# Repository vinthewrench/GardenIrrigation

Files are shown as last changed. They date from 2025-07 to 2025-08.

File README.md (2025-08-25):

# GardenIrrigation

This is the hardware for Farm automation made easy as Pi

The entire series is at https://www.vinthewrench.com/p/off-grid-farm-automation-raspberry-pi

Garden Irrigation Board

<object data="Garden PCB schematic.pdf" type="application/pdf" width="600px" height="500px">
    <embed src="Garden PCB schematic.pdf">
        <p>This browser does not support PDFs. Please download the PDF to view it: <a href="Garden PCB schematic.pdf">Download PDF</a>.</p>
    </embed>
</object>

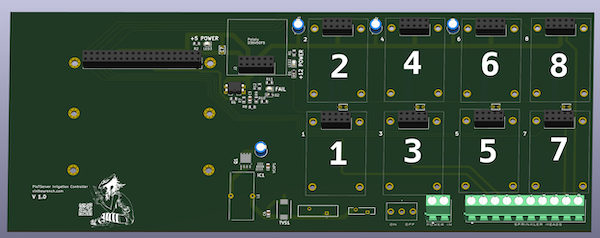
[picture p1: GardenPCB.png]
Garden Irrigation Board


DRV103 Plugin Board

<object data="DRV103 Solenoid Driver Board.pdf" type="application/pdf" width="600px" height="500px">
    <embed src="DRV103 Solenoid Driver Board.pdf">
        <p>This browser does not support PDFs. Please download the PDF to view it: <a href="DRV103 Solenoid Driver Board.pdf">Download PDF</a>.</p>
    </embed>
</object>

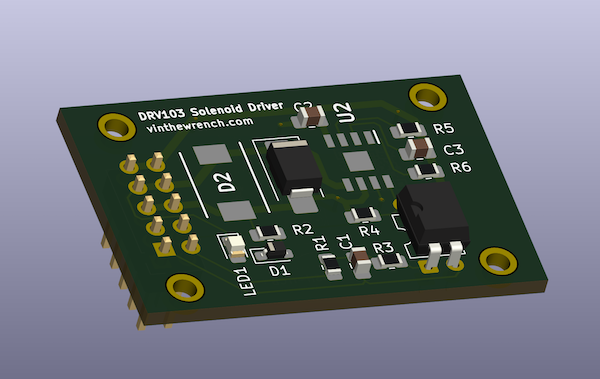
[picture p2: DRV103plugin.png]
DRV 103 Plugin


# Articles

* [Farm automation made easy as Pi](https://www.vinthewrench.com/p/raspberry-pi-internet-of-things-part)
* [Controlling the Irrigation valves.](https://www.vinthewrench.com/p/raspberry-pi-internet-of-things-part-23c)
* [Reading the Temperature with 1-wire Sensors](https://www.vinthewrench.com/p/raspberry-pi-internet-of-things-part-a4c)
* [Using the I2C protocol to communicate to sensors.](https://www.vinthewrench.com/p/raspberry-pi-internet-of-things-part-688)
* [Reading Environmental Data with I2C](https://www.vinthewrench.com/p/raspberry-pi-internet-of-things-part-a03)
* [Rain Sensors](https://www.vinthewrench.com/p/raspberry-pi-internet-of-things-part-cfd)
* [More I/O](https://www.vinthewrench.com/p/raspberry-pi-internet-of-things-part-61b)
* [Getting the data and controlling the devices from the REST API](https://www.vinthewrench.com/p/raspberry-pi-internet-of-things-part-8e7)
* [Writing your own device plug-ins](https://www.vinthewrench.com/p/raspberry-pi-internet-of-things-part-9ef)
* [Using software devices to build on the hardware.](https://www.vinthewrench.com/p/raspberry-pi-internet-of-things-part-094)
* [How to make things happen automatically](https://www.vinthewrench.com/p/raspberry-pi-internet-of-things-part-12f)
* [How to make things happen on time](https://www.vinthewrench.com/p/raspberry-pi-internet-of-things-part-eb8)
* [There are always conditions to evaluate](https://www.vinthewrench.com/p/raspberry-pi-internet-of-things-part-3aa)
* [Rolling my own I²C and 1-Wire interface card](https://www.vinthewrench.com/p/raspberry-pi-internet-of-things-part-2a8)

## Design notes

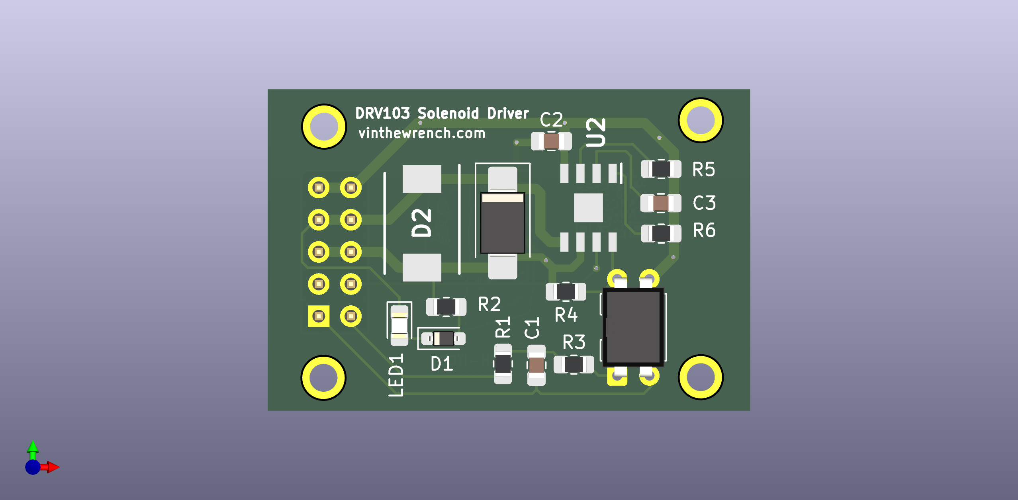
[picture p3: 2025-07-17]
DRV103 plugin/drvplugin.png

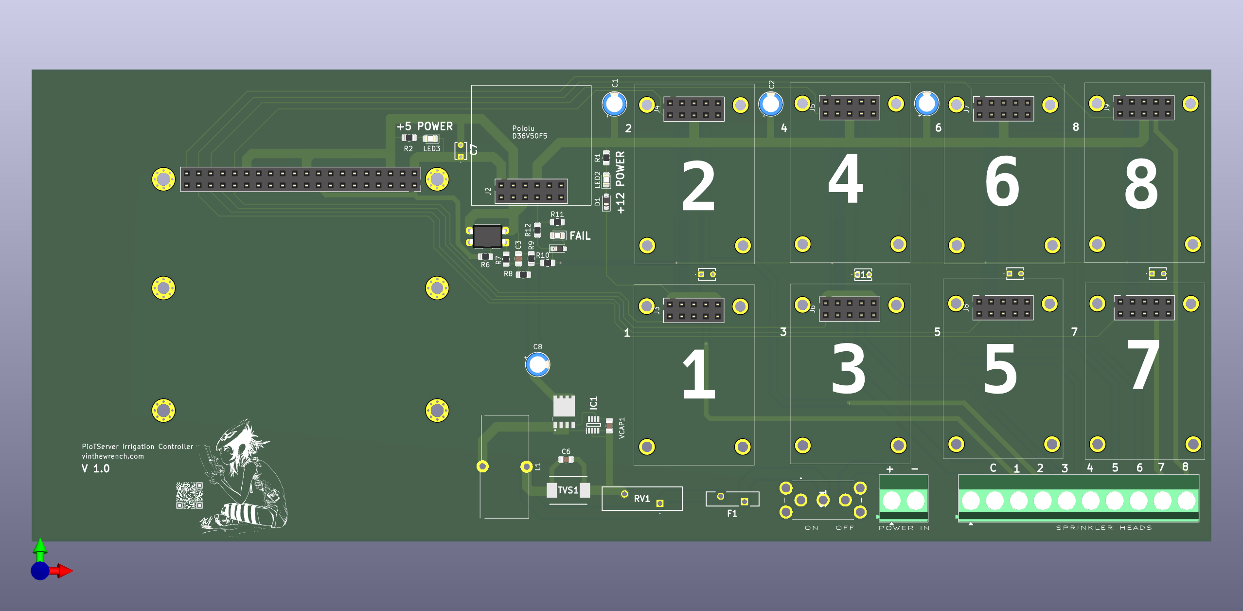
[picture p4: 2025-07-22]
Garden PCB/Garden PCB.png

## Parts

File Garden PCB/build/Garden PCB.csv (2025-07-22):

Id | Designator | Footprint | Quantity | Designation | Supplier and ref
1 | TVS1 | DIONM7959X262N | 1 | SMCJ60CA
2 | VCAP1,C6 | C_0805_2012Metric_Pad1.18x1.45mm_HandSolder | 2 | .1uf
3 | J8,J9,J5,J7,J3,J10,J6,J4 | PinSocket_2x05_P2.54mm_Vertical | 8 | Conn_02x05_Odd_Even
4 | LED1 | LED_0805_2012Metric_Pad1.15x1.40mm_HandSolder | 1 | APT2012SURCK
5 | J1 | PinSocket_2x20_P2.54mm_Vertical | 1 | GPIO
6 | C3 | C_0805_2012Metric_Pad1.18x1.45mm_HandSolder | 1 | .68uf
7 | R7 | R_0805_2012Metric_Pad1.20x1.40mm_HandSolder | 1 | 100
8 | D1,D2 | D_SOD-323_HandSoldering | 2 | 1N4148WS-7-F
9 | R8 | R_0805_2012Metric_Pad1.20x1.40mm_HandSolder | 1 | 150
10 | LED3,LED2 | LED_0805_2012Metric_Pad1.15x1.40mm_HandSolder | 2 | LG M67K-H1J2-24-Z
11 | C10,C11,C7,C5,C9 | RCER71H104K0DBH03A | 5 | .1uf
12 | R12 | R_0805_2012Metric_Pad1.20x1.40mm_HandSolder | 1 | 6.8K
13 | U1 | DIP-4_W7.62mm | 1 | PC817
14 | C1,C2,C4 | CP_Radial_D5.0mm_P2.00mm | 3 | 10uf
15 | C8 | CP_Radial_D5.0mm_P2.00mm | 1 | 220uf
16 | RV1 | V14E14AUTO | 1 | V14E14AUTO
17 | IC1 | SOT65P280X110-8N | 1 | LM74500QDDFRQ1
18 | L1 | L_Toroid_Vertical_L21.6mm_W9.1mm_P8.40mm_Bourns_5700 | 1 | 10 uH
19 | J2 | PinSocket_2x06_P2.54mm_Vertical | 1 | Conn_02x06_Top_Bottom
20 | F1 | RXEF0902 | 1 | RXEF090
21 | SW1 | 7105SYV3QE | 1 | SW_SPST
22 | R10 | R_0805_2012Metric_Pad1.20x1.40mm_HandSolder | 1 | 3.3K
23 | Q1 | CSD18532Q5BT | 1 | CSD18532Q5BT
24 | J12 | TerminalBlock_Phoenix_MKDS-1,5-2-5.08_1x02_P5.08mm_Horizontal | 1 | Screw_Terminal_01x02
25 | R2 | R_0805_2012Metric_Pad1.20x1.40mm_HandSolder | 1 | 330
26 | R1,R11 | R_0805_2012Metric_Pad1.20x1.40mm_HandSolder | 2 | 5.6K
27 | J11 | TerminalBlock_Phoenix_MKDS-1,5-10-5.08_1x10_P5.08mm_Horizontal | 1 | Screw_Terminal_01x10
28 | R9 | R_0805_2012Metric_Pad1.20x1.40mm_HandSolder | 1 | 1.8K
29 | R6 | R_0805_2012Metric_Pad1.20x1.40mm_HandSolder | 1 | 10K
30 | RP? | raspberrypi_2_3 | 1 | Raspberry_Pi_2_3

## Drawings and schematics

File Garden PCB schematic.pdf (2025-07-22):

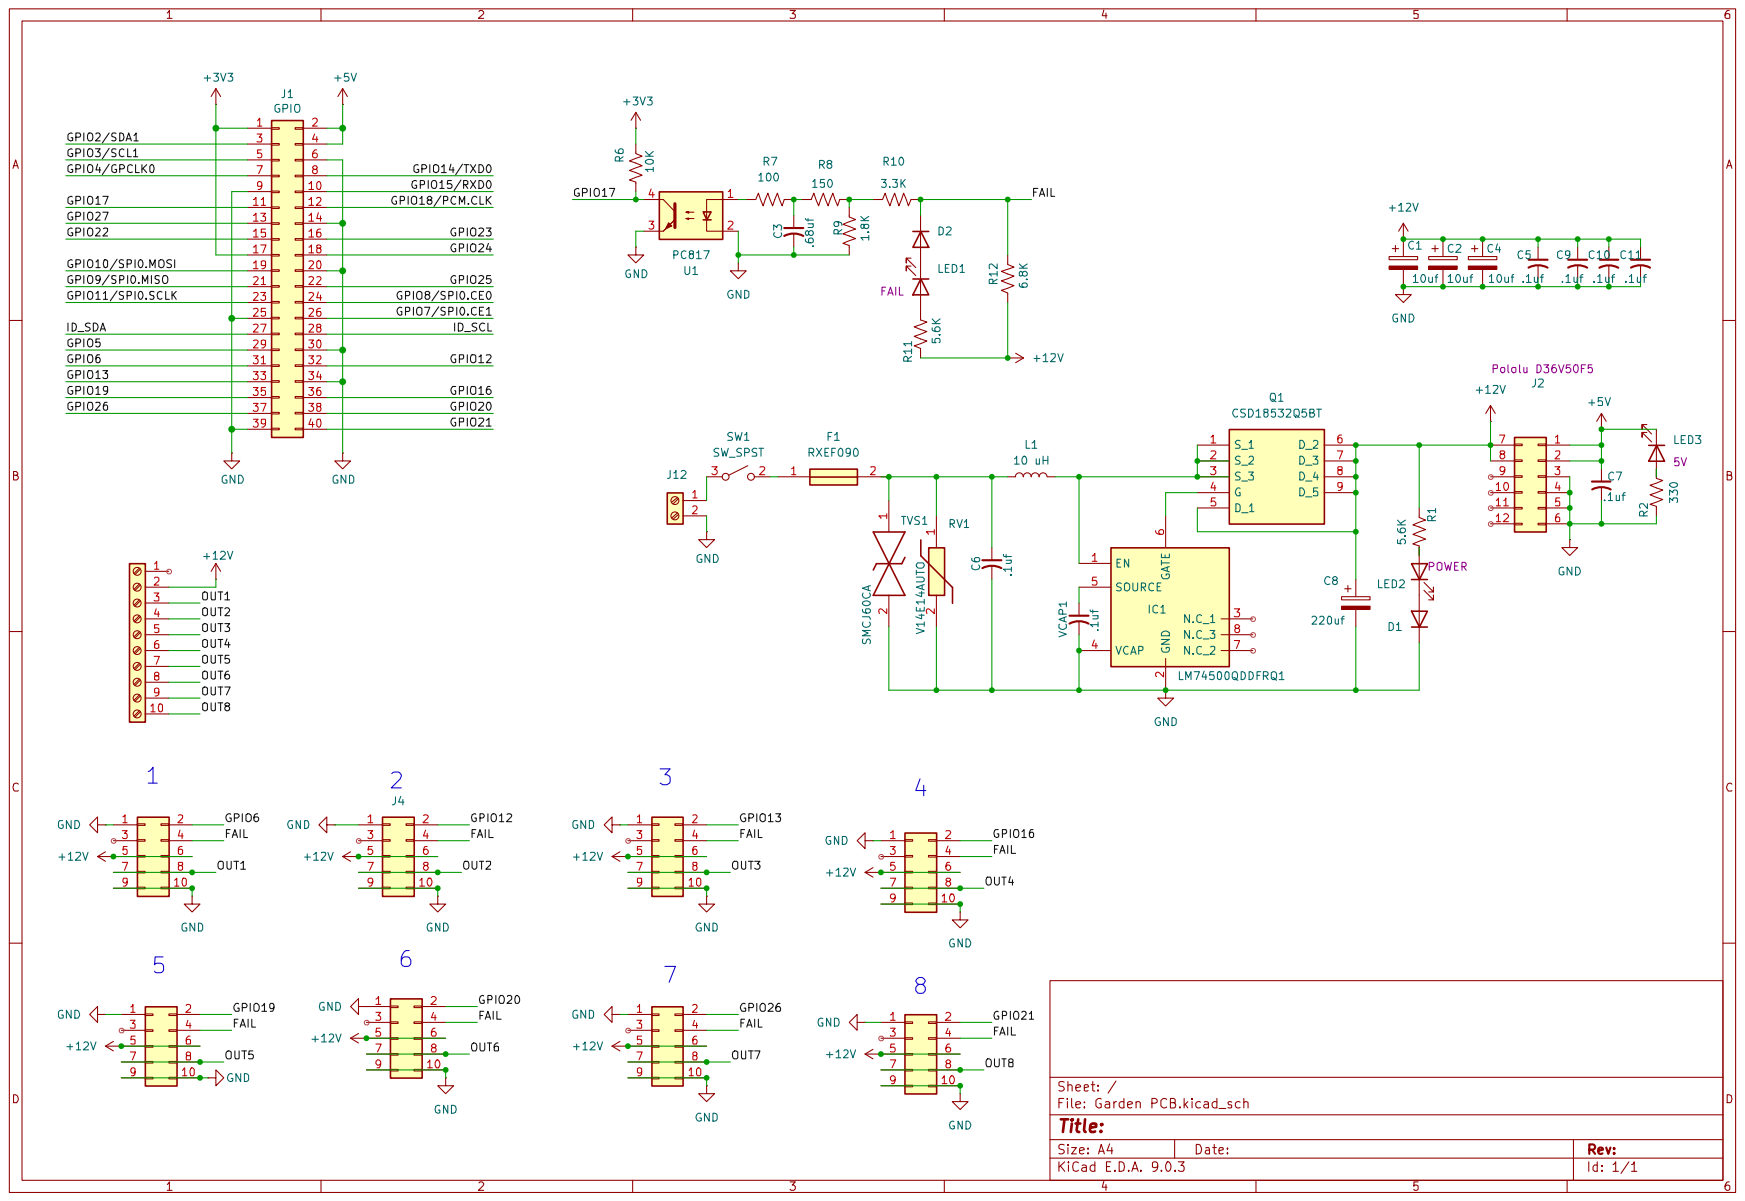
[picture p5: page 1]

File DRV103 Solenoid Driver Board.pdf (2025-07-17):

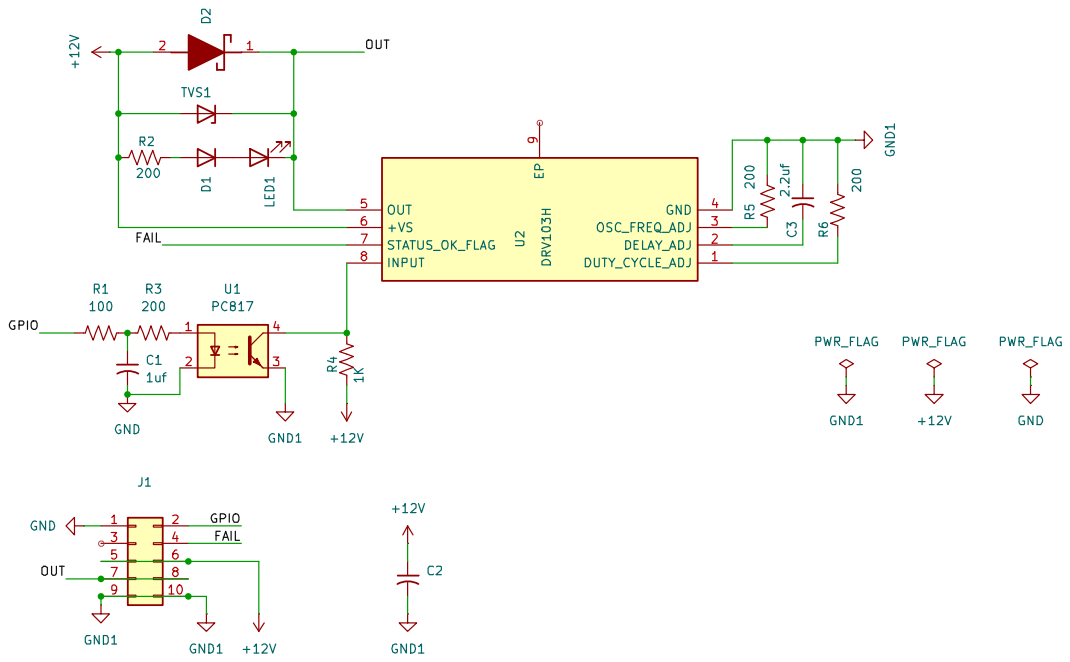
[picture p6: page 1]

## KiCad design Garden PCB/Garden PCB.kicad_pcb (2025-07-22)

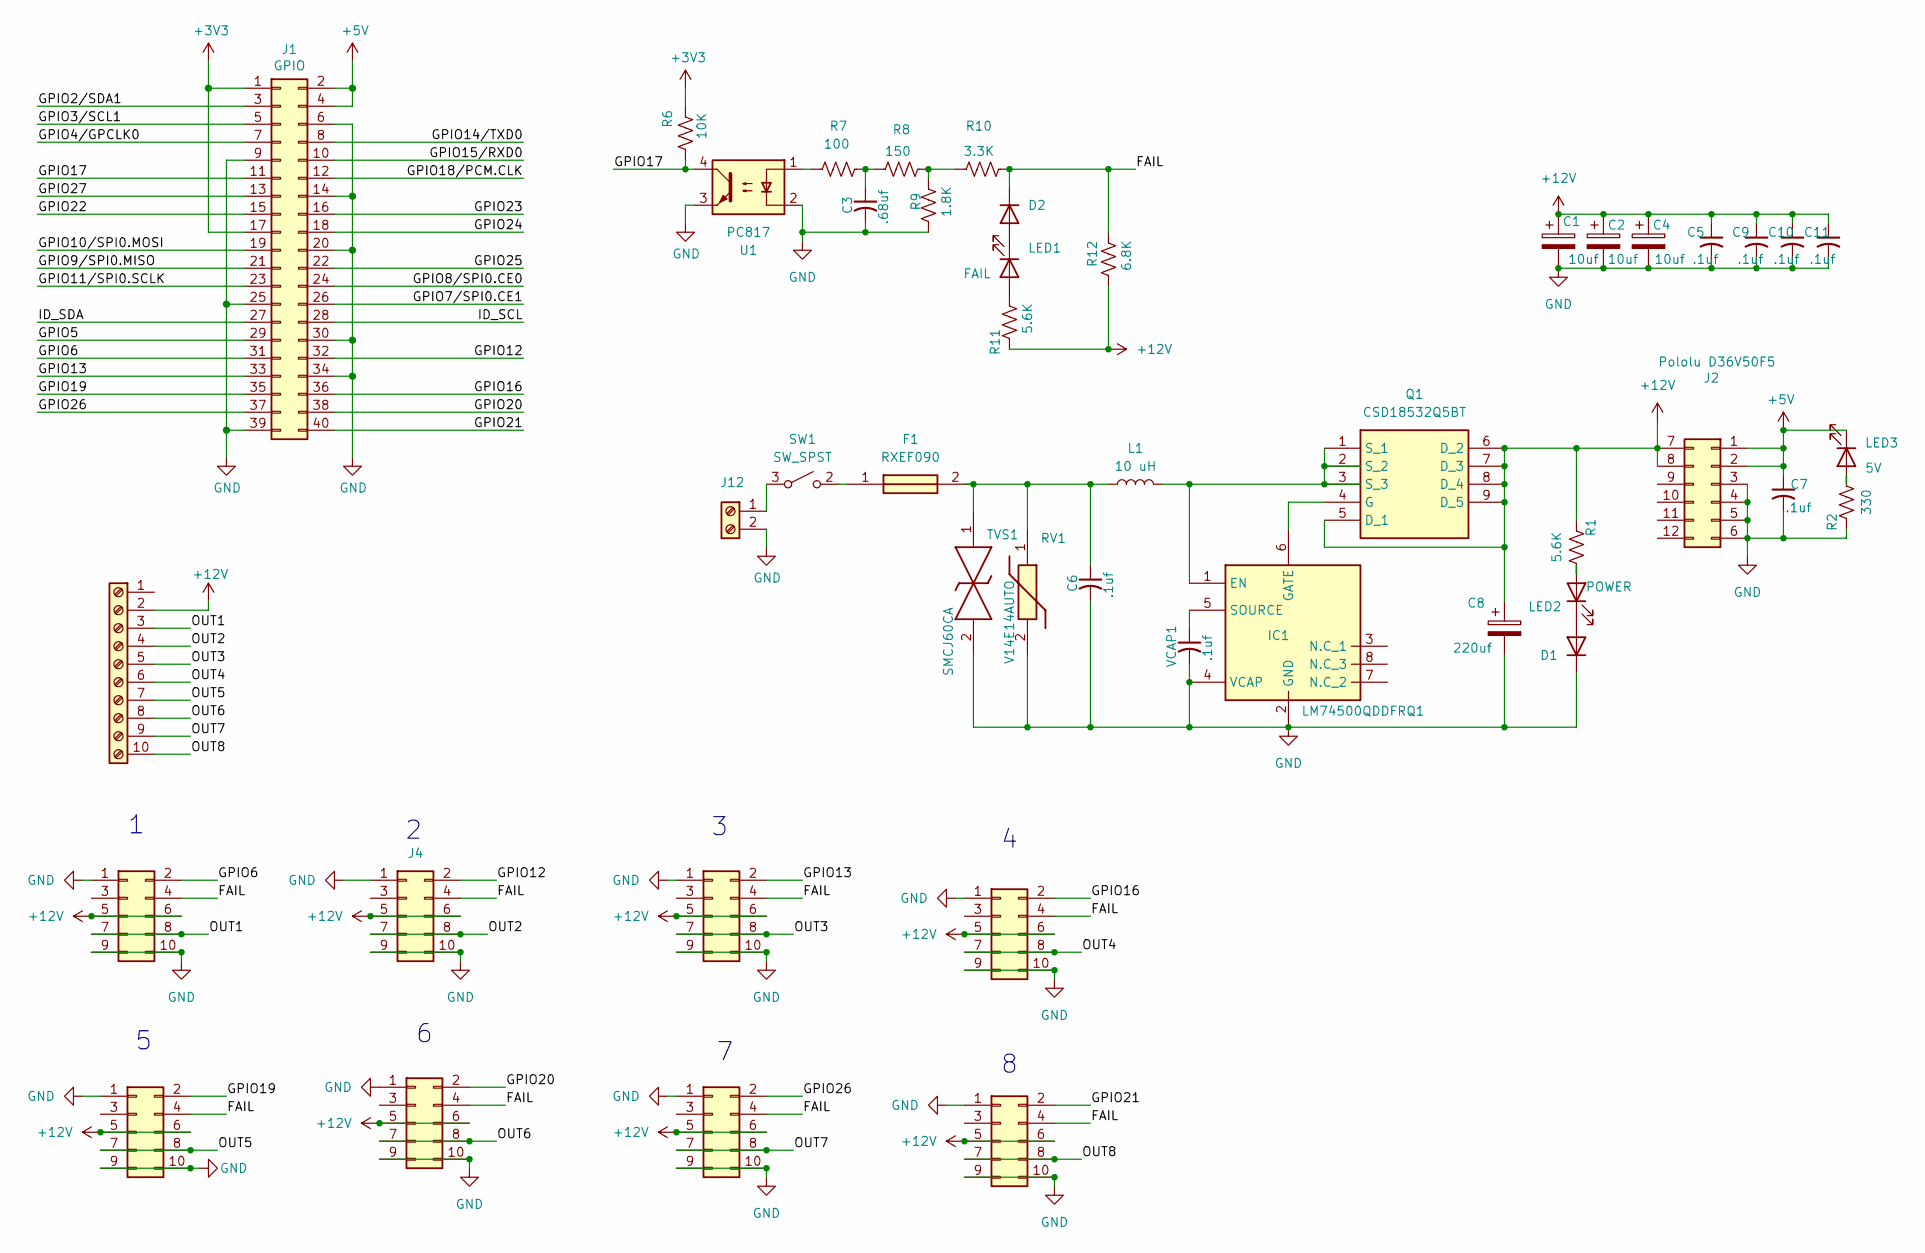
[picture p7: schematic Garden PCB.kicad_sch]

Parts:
C1, C2, C4: 10uf; CP_Radial_D5.0mm_P2.00mm
C3: .68uf; C_0805_2012Metric_Pad1.18x1.45mm_HandSolder
C5, C7, C9, C10, C11: .1uf; RCER71H104K0DBH03A
C6: .1uf; C_0805_2012Metric_Pad1.18x1.45mm_HandSolder
C8: 220uf; CP_Radial_D5.0mm_P2.00mm
D1, D2: 1N4148WS-7-F; D_SOD-323_HandSoldering
F1: RXEF090; RXEF0902; Manufacturer_Part_Number RXEF090-2; Mouser Part Number 650-RXEF090-2
IC1: LM74500QDDFRQ1; SOT65P280X110-8N; Mouser Part Number 595-LM74500QDDFRQ1
J1: GPIO; PinSocket_2x20_P2.54mm_Vertical
J2: Conn_02x06_Top_Bottom; PinSocket_2x06_P2.54mm_Vertical
J3, J4, J5, J6, J7, J8, J9, J10: Conn_02x05_Odd_Even; PinSocket_2x05_P2.54mm_Vertical
J11: Screw_Terminal_01x10; TerminalBlock_Phoenix_MKDS-1,5-10-5.08_1x10_P5.08mm_Horizon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
J12: Screw_Terminal_01x02; TerminalBlock_Phoenix_MKDS-1,5-2-5.08_1x02_P5.08mm_Horizont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
L1: 10 uH; L_Toroid_Vertical_L21.6mm_W9.1mm_P8.40mm_Bourns_5700
LED1: APT2012SURCK; LED_0805_2012Metric_Pad1.15x1.40mm_HandSolder
LED2, LED3: LG M67K-H1J2-24-Z; LED_0805_2012Metric_Pad1.15x1.40mm_HandSolder
Q1: CSD18532Q5BT; Manufacturer_Part_Number CSD18532Q5BT; Mouser Part Number 595-CSD18532Q5BT
R1, R11: 5.6K; R_0805_2012Metric_Pad1.20x1.40mm_HandSolder
R2: 330; R_0805_2012Metric_Pad1.20x1.40mm_HandSolder
R6: 10K; R_0805_2012Metric_Pad1.20x1.40mm_HandSolder
R7: 100; R_0805_2012Metric_Pad1.20x1.40mm_HandSolder
R8: 150; R_0805_2012Metric_Pad1.20x1.40mm_HandSolder
R9: 1.8K; R_0805_2012Metric_Pad1.20x1.40mm_HandSolder
R10: 3.3K; R_0805_2012Metric_Pad1.20x1.40mm_HandSolder
R12: 6.8K; R_0805_2012Metric_Pad1.20x1.40mm_HandSolder
RV1: V14E14AUTO; Manufacturer_Part_Number V14E14AUTO; Mouser Part Number 576-V14E14AUTO
SW1: SW_SPST; 7105SYV3QE
TVS1: SMCJ60CA; DIONM7959X262N; Manufacturer_Part_Number SMCJ60CA; Mouser Part Number 652-SMCJ60CA
U1: PC817; DIP-4_W7.62mm
VCAP1: .1uf; C_0805_2012Metric_Pad1.18x1.45mm_HandSolder

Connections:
+3V3: J1.1, J1.17, R6.2
+5V: C7.1, J1.2, J1.4, J2.1, J2.2, LED3.1 (K)
+12V: C1.1, C2.1, C4.1, C5.1, C8.1, C9.1, C10.1, C11.1, J2.7, J2.8, J3.5, J3.6, J4.5, J4.6, J5.5, J5.6, J6.5, J6.6, J7.5, J7.6, J8.5, J8.6, J9.5, J9.6, J10.5, J10.6, J11.2, Q1.5 (D_1), Q1.6 (D_2), Q1.7 (D_3), Q1.8 (D_4), Q1.9 (D_5), R1.1, R11.1, R12.1
/FAIL: D2.1 (K), J3.4, J4.4, J5.4, J6.4, J7.4, J8.4, J9.4, J10.4, R10.2, R12.2
/GPIO2/SDA1: J1.3
/GPIO3/SCL1: J1.5
/GPIO4/GPCLK0: J1.7
/GPIO5: J1.29
/GPIO6: J1.31, J3.2
/GPIO7/SPI0.CE1: J1.26
/GPIO8/SPI0.CE0: J1.24
/GPIO9/SPI0.MISO: J1.21
/GPIO10/SPI0.MOSI: J1.19
/GPIO11/SPI0.SCLK: J1.23
/GPIO12: J1.32, J4.2
/GPIO13: J1.33, J6.2
/GPIO14/TXD0: J1.8
/GPIO15/RXD0: J1.10
/GPIO16: J1.36, J5.2
/GPIO17: J1.11, R6.1, U1.4
/GPIO18/PCM.CLK: J1.12
/GPIO19: J1.35, J8.2
/GPIO20: J1.38, J7.2
/GPIO21: J1.40, J9.2
/GPIO22: J1.15
/GPIO23: J1.16
/GPIO24: J1.18
/GPIO25: J1.22
/GPIO26: J1.37, J10.2
/GPIO27: J1.13
/ID_SCL: J1.28
/ID_SDA: J1.27
/OUT1: J3.7, J3.8, J11.3
/OUT2: J4.7, J4.8, J11.4
/OUT3: J6.7, J6.8, J11.5
/OUT4: J5.7, J5.8, J11.6
/OUT5: J8.7, J8.8, J11.7
/OUT6: J7.7, J7.8, J11.8
/OUT7: J10.7, J10.8, J11.9
/OUT8: J9.7, J9.8, J11.10
GND: C1.2, C2.2, C3.2, C4.2, C5.2, C6.2, C7.2, C8.2, C9.2, C10.2, C11.2, D1.1 (K), IC1.2 (GND), IC1.4 (VCAP), J1.6, J1.9, J1.14, J1.20, J1.25, J1.30, J1.34, J1.39, J2.3, J2.4, J2.5, J2.6, J3.1, J3.9, J3.10, J4.1, J4.9, J4.10, J5.1, J5.9, J5.10, J6.1, J6.9, J6.10, J7.1, J7.9, J7.10, J8.1, J8.9, J8.10, J9.1, J9.9, J9.10, J10.1, J10.9, J10.10, J12.2, R2.1, R9.2, RV1.2, TVS1.2, U1.2, U1.3, VCAP1.2
unnamed: C3.1, R7.2, R8.1
unnamed: C6.1, F1.2, L1.1, RV1.1, TVS1.1
unnamed: D1.2 (A), LED2.1 (K)
unnamed: D2.2 (A), LED1.1 (K)
unnamed: IC1.1 (EN), L1.2, Q1.1 (S_1), Q1.2 (S_2), Q1.3 (S_3)
unnamed: IC1.6 (GATE), Q1.4 (G)
unnamed: IC1.5 (SOURCE), VCAP1.1
unnamed: J12.1, SW1.3 (A)
unnamed: LED1.2 (A), R11.2
unnamed: LED2.2 (A), R1.2
unnamed: LED3.2 (A), R2.2
unnamed: R7.1, U1.1
unnamed: R8.2, R9.1, R10.1
unnamed: F1.1, SW1.2 (B)

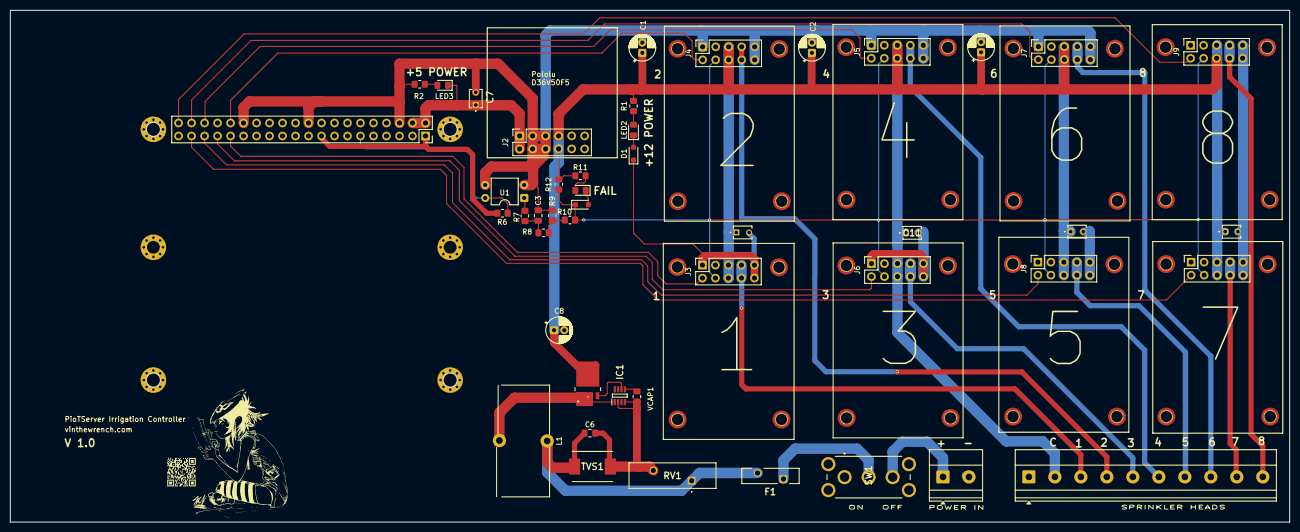
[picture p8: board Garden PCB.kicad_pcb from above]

Board: 2 copper layers, 250.0 x 100.0 mm, 53 parts (1 on the bottom side), 36 nets.

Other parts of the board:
MH1, MH2, MH3, MH4, MH5, MH6: MountingHole_2.5mm_Pad_Via
RP?: Raspberry_Pi_2_3; raspberrypi_2_3

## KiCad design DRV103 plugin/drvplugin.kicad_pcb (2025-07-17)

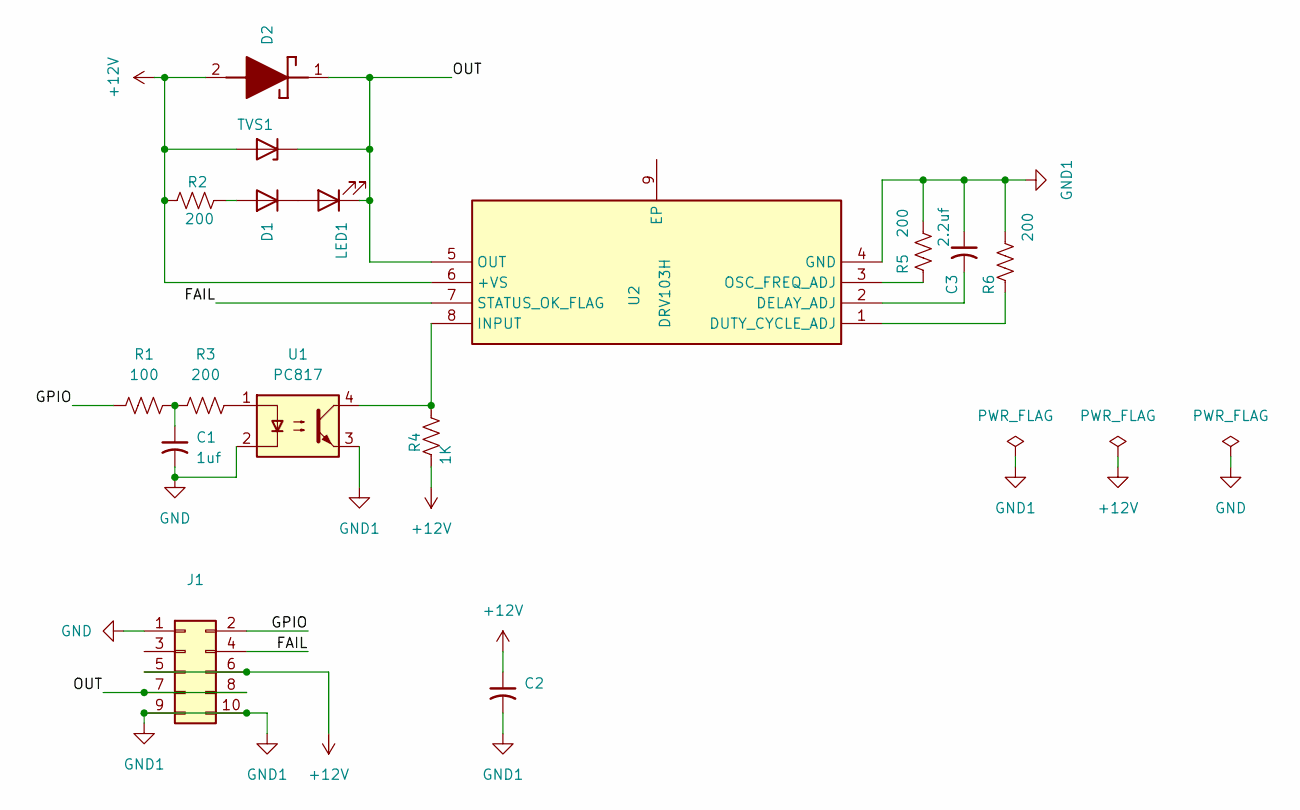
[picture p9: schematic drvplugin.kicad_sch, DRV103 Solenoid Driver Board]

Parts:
C1: 1uf; C_0805_2012Metric_Pad1.18x1.45mm_HandSolder
C2: .1uf; C_0805_2012Metric_Pad1.18x1.45mm_HandSolder
C3: 2.2uf; C_0805_2012Metric_Pad1.18x1.45mm_HandSolder
D1: 1N4148; D_SOD-323_HandSoldering
D2: VS-30BQ040; DIOM7959X262N; Mouser Part Number 583-SR340-T
J1: Conn_02x05_Odd_Even; PinHeader_2x05_P2.54mm_Vertical
LED1: LG M67K-H1J2-24-Z; LED_0805_2012Metric_Pad1.15x1.40mm_HandSolder
R1: 100; R_0805_2012Metric_Pad1.20x1.40mm_HandSolder
R2, R3, R5, R6: 200; R_0805_2012Metric_Pad1.20x1.40mm_HandSolder
R4: 1K; R_0805_2012Metric_Pad1.20x1.40mm_HandSolder
TVS1: P6SMB18A; D_SMB_Handsoldering
U1: PC817; DIP-4_W7.62mm
U2: DRV103H; SOIC127P600X170-9N; Mouser Part Number 595-DRV103H

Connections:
+12V: C2.1, D2.2 (A), J1.5, J1.6, R2.1, R4.1, TVS1.2 (A), U2.6 (+VS)
/FAIL: J1.4, U2.7 (STATUS_OK_FLAG)
/GPIO: J1.2, R1.2
/OUT: D2.1 (K), J1.7, J1.8, LED1.1 (K), TVS1.1 (K), U2.5 (OUT)
GND: C1.2, J1.1, U1.2
GND1: C2.2, C3.1, J1.9, J1.10, R5.2, R6.2, U1.3, U2.4 (GND)
unnamed: C1.1, R1.1, R3.2
unnamed: D1.2 (A), R2.2
unnamed: D1.1 (K), LED1.2 (A)
unnamed: R3.1, U1.1
unnamed: C3.2, U2.2 (DELAY_ADJ)
unnamed: R6.1, U2.1 (DUTY_CYCLE_ADJ)
unnamed: R4.2, U1.4, U2.8 (INPUT)
unnamed: R5.1, U2.3 (OSC_FREQ_ADJ)

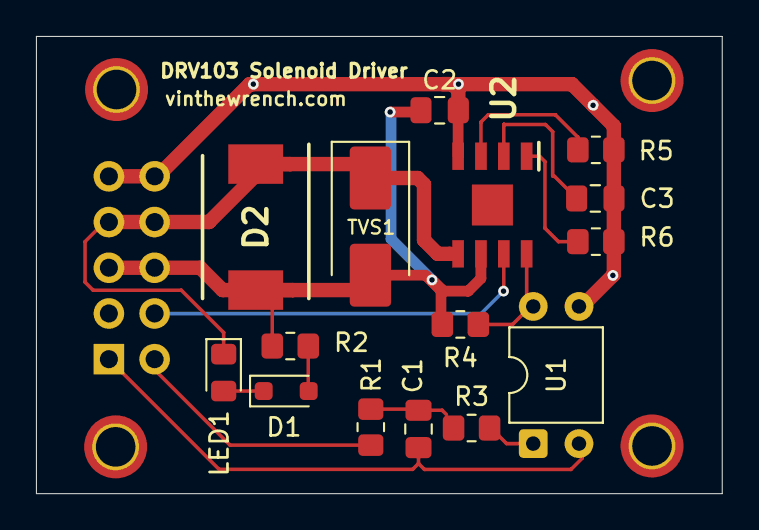
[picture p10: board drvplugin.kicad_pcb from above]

Board: 2 copper layers, 38.1 x 25.4 mm, 16 parts (1 on the bottom side), 14 nets.

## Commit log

2025-07-17 better readme
    [drvplugin.kicad_sch]
2025-07-22 fixes for power switch, also looks like KiCad might have boned some of our pinouts
    [Garden PCB-B_Cu.gbr, Garden PCB-B_Mask.gbr, Garden PCB-B_Paste.gbr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]
